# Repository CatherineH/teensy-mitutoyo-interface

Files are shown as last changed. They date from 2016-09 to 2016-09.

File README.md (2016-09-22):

# teensy-mitutoyo-interface
An interface to Mitutoyo dial indicators from a teensy

Originally based off of an [instructable](http://www.instructables.com/id/Interfacing-a-Digital-Micrometer-to-a-Microcontrol/) by [Steve Spence](http://arduinotronics.blogspot.com/).

For more details, check out [my blog post](http://catherineh.github.io/programming/2016/09/21/teensy-mitutoyo-interface.html) about this project.

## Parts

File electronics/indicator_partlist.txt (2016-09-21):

Partlist

Exported from mitsuyo_interface.sch at 8/31/16 2:12 PM

EAGLE Version 7.5.0 Copyright (c) 1988-2015 CadSoft

Assembly variant: 

Part      Value           Device          Package        Library                            Sheet

INDICATOR 302-S101        302-S101        302-S101       connectors                         1
R1        10k             R-US_R0805      R0805          resistor                           1
T1        2N2222          2N2222          TO92-EBC-OVAL  adafruit                           1
TEENSY    TEENSY_LC_MOTOR TEENSY_LC_MOTOR TEENSYLC-MOTOR Teensy_3_and_LC_Series_Boards_v1.1 1

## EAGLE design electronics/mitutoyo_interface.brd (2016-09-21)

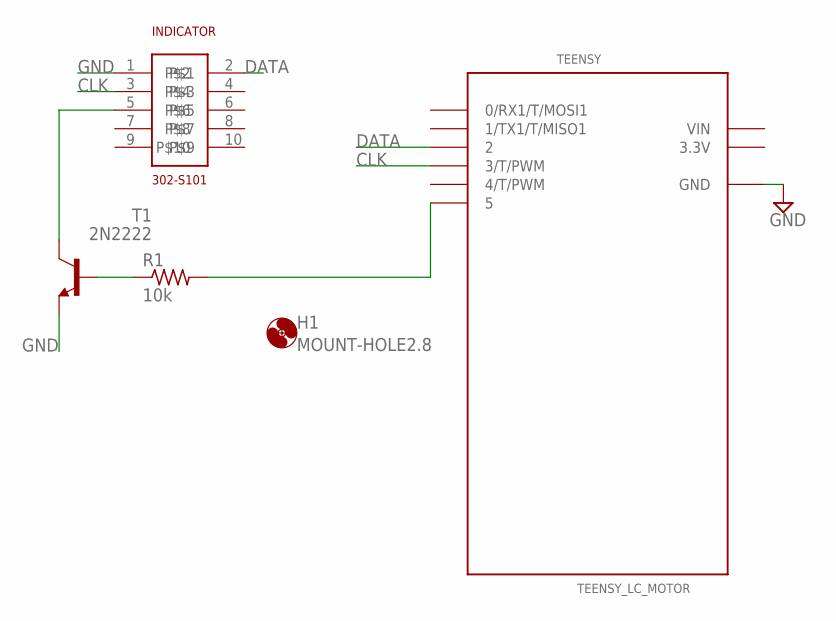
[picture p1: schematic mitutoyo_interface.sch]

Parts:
H1: MOUNT-HOLE2.8; 2,8
INDICATOR: 302-S101
R1: 10k; R0805
T1: 2N2222; TO92-EBC-OVAL
TEENSY: TEENSY_LC_MOTOR; TEENSYLC-MOTOR

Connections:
3.3V: TEENSY.3.3V
CLK: INDICATOR.3, TEENSY.3 (3/T/PWM)
DATA: INDICATOR.2, TEENSY.2
GND: INDICATOR.1, T1.E, TEENSY.GND
unnamed: INDICATOR.5, T1.C
unnamed: R1.1, T1.B
unnamed: R1.2, TEENSY.5
VIN: TEENSY.VIN

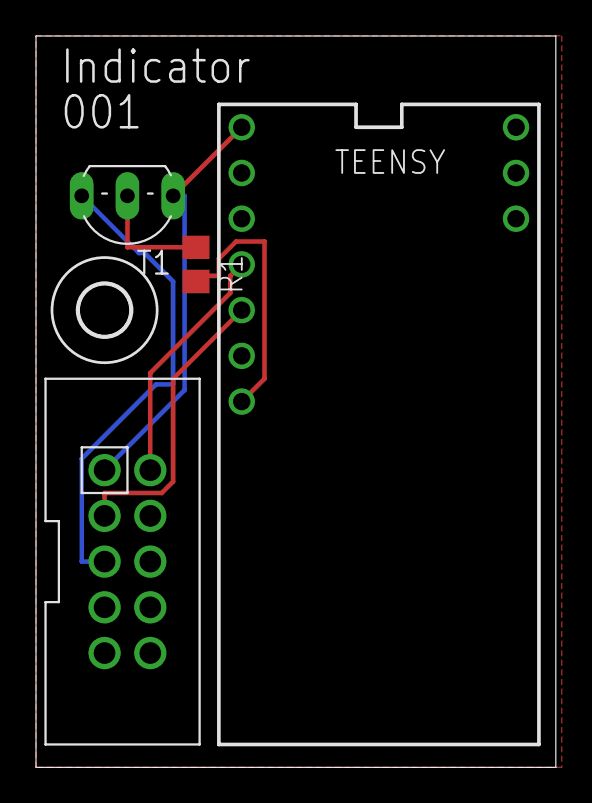
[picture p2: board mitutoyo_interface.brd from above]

Board: 2 copper layers, 28.9 x 40.6 mm, 5 parts (0 on the bottom side), 6 nets.

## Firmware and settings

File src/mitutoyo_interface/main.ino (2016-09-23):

#include "scpi_comm.h"
#include "struct_definitions.h"

mitutoyo_interface _interface = {.raw_data = {0, 0, 0, 0, 0, 0, 0, 0, 0, 0, 0, 0, 0},
                                 .acknowledge = 0, .number = 0L, .sign = 0,
                                 .decimal = 0, .units = 0, .good_reading = 0};

int req = 5; //mic REQ line goes to pin 5 through q1 (arduino high pulls request line low)
int dat = 2; //mic Data line goes to pin 2
int clk = 3; //mic Clock line goes to pin 3
int led = 13;


void setup() {
    Serial.begin(9600);
    pinMode(req, OUTPUT);
    pinMode(clk, INPUT_PULLUP);
    pinMode(dat, INPUT_PULLUP);
    pinMode(led, OUTPUT);
    digitalWrite(req, LOW); // set request at LOW
}

void loop() { // get data from mic
    if(_interface.good_reading == 0)
    {
        // if our last reading was bad, try to recover by waiting for a bit.
        digitalWrite(req, LOW);
        digitalWrite(led, LOW);
        delay(10);
    }
    digitalWrite(req, HIGH); // generate set request
    digitalWrite(led, HIGH);
    _interface.good_reading = 1;
    for(int i = 0; i < 13; i++ ) {
        int k = 0;
        for (int j = 0; j < 4; j++) {
            while( digitalRead(clk) == LOW) { } // hold until clock is high
            while( digitalRead(clk) == HIGH) { } // hold until clock is low
            bitWrite(k, j, (digitalRead(dat) & 0x1)); // read data bits, and reverse order
        }
        // if the
        // error correction: if the first four bytes aren't 15, restart.
        if( i<4 && k != 15)
        {
            //digitalWrite(req, LOW);
            //digitalWrite(led, LOW);
            _interface.good_reading = 0;
        }
        if(_interface.good_reading){
            // extract data
            _interface.raw_data[i] = k;
        }
    }
    _interface.sign = _interface.raw_data[4];
    _interface.decimal = _interface.raw_data[12];
    _interface.units = _interface.raw_data[11];
    // assemble measurement from bytes
    char buf[7];
    for(int lp = 0;lp < 6; lp++ )
    {
        buf[lp]=_interface.raw_data[lp+5]+'0';
    }
    buf[6] = 0;
    _interface.number = atol(buf);
    if (Serial.available() > 0) {
        comm_protocol(Serial.read(), &_interface);
    }
}

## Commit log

2016-09-21 added source code
    [mitsuyo_interface.brd, mitsuyo_interface.sch]
2016-09-22 added blog post to readme
    [mitutoyo_interface.brd, mitutoyo_interface.sch]
